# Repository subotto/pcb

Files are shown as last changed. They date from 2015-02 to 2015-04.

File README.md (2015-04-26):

# pcb
Progetto in EAGLE-EAD per la scheda integrata
situazione (26/04/15)

Il repo contiene tre progetti Eagle (la versione freeware non mi consente di riunirli in uno solo, per ora)
- power_board: è la scheda di alimenazione PoE, già stampata e realizzata. L'abbiamo usata l'ultima volta.
- sub_081 / 082: sono gli schemi per i nuovi circuiti delle fotocellule ideati da Francesco Hoch e sviluppati da lui e me. Lo schema 081 implementa l'amplificatore / comparatore con due opamp (TL081), lo schema 082 li riunisce in un singolo integrato (TL082) per economia di spazio e di costi. Prima della 24ore lo schema è stato testato con successo su breadboard (con due uA741, perché quello avevamo), ma non ho fatto in tempo a finire di diseagnare e realizzare la scheda completa e dunque abbiamo ripiegato su quelle di Guatieri, come ben ricordate.

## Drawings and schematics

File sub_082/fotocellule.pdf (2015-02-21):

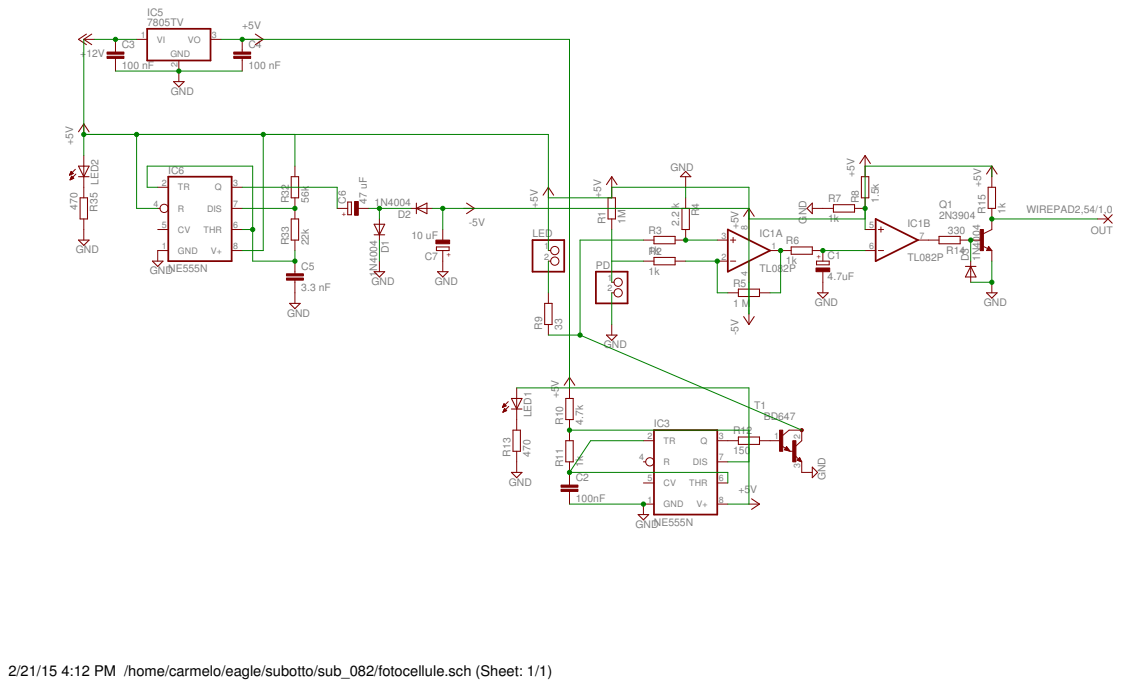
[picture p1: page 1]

2/21/15 4:12 PM /home/carmelo/eagle/subotto/sub_082/fotocellule.sch (Sheet: 1/1)

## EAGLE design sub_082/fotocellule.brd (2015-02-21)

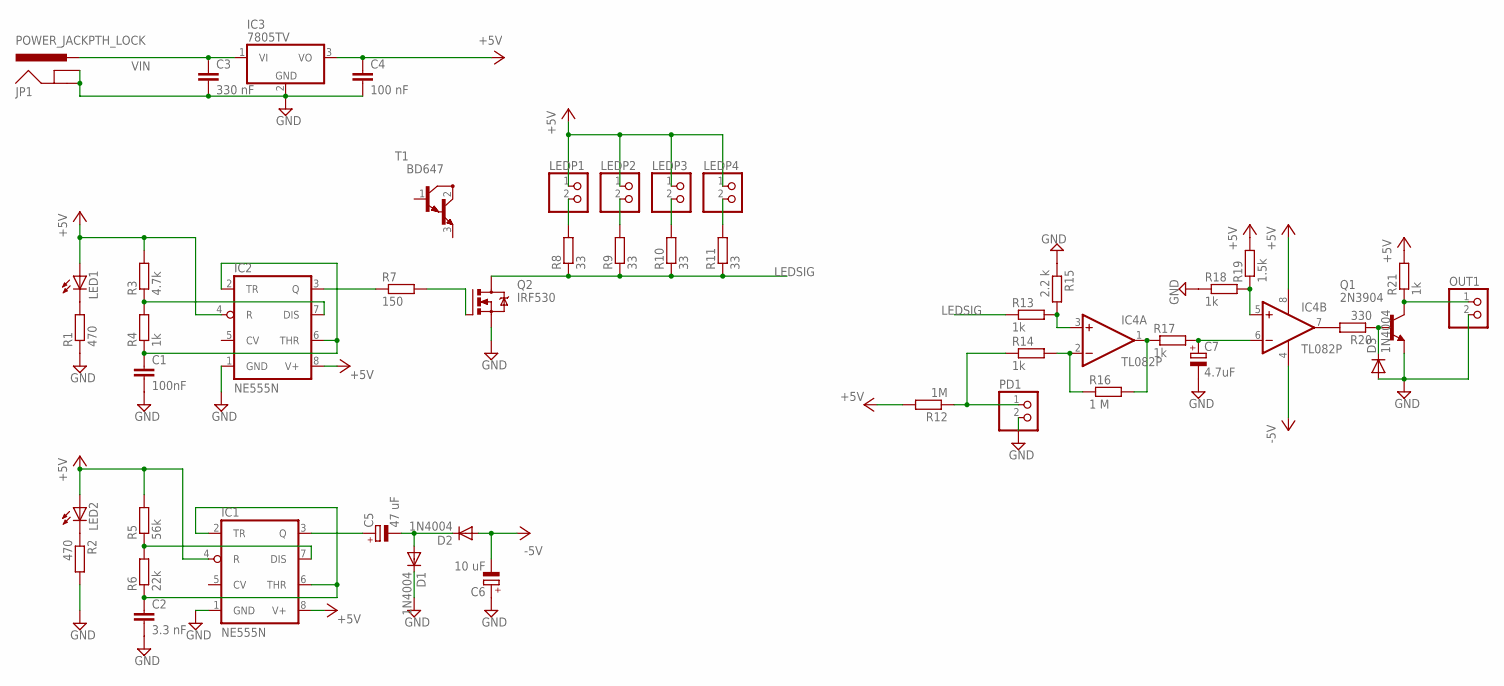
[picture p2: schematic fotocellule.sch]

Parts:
C1: 100nF; C025-024X044
C2: 3.3 nF; C025-024X044
C3: 330 nF; C025-024X044
C4: 100 nF; C025-024X044
C5: 47 uF; E2,5-5
C6: 10 uF; E2,5-5
C7: 4.7uF; E2,5-6
D1, D2, D3: 1N4004; DO41-10
IC1, IC2: NE555N; DIL08
IC3: 7805TV; TO220V
IC4: TL082P; DIL08
JP1: POWER_JACKPTH_LOCK; POWER_JACK_PTH_LOCK
LED1, LED2: LED5MM
LEDP1, LEDP2, LEDP3, LEDP4: PINHD-1X2; 1X02
OUT1: PINHD-1X2; 1X02
PD1: PINHD-1X2; 1X02
Q1: 2N3904; TO92
Q2: IRF530; TO220BV
R1, R2: 470; 0207/10
R3: 4.7k; 0207/10
R4, R13, R14, R17, R18, R21: 1k; 0207/10
R5: 56k; 0207/10
R6: 22k; 0207/10
R7: 150; 0207/10
R8, R9, R10, R11: 33; 0207/10
R12: 1M; 0207/10
R15: 2.2 k; 0207/10
R16: 1 M; 0207/10
R19: 1.5k; 0207/10
R20: 330; 0207/10
T1: BD647; TO220

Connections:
+5V: C4.1, IC1.4 (R), IC1.8 (V+), IC2.4 (R), IC2.8 (V+), IC3.3 (VO), IC4.8 (V+), LED1.A, LED2.A, LEDP1.1, LEDP2.1, LEDP3.1, LEDP4.1, R3.2, R5.2, R12.2, R19.2, R21.2
-5V: C6.-, D2.A, IC4.4 (V-)
GND: C1.2, C2.2, C3.2, C4.2, C6.+, C7.-, D1.C, D3.A, IC1.1 (GND), IC2.1 (GND), IC3.2 (GND), JP1.GND, JP1.GNDBREAK, OUT1.2, PD1.2, Q1.3 (E), Q2.S, R1.1, R2.2, R15.1, R18.1
LEDSIG: Q2.D, R8.1, R9.1, R10.1, R11.1, R13.1
unnamed: C1.1, IC2.2 (TR), IC2.6 (THR), R4.1
unnamed: IC2.7 (DIS), R3.1, R4.2
unnamed: IC4.3 (+IN), R13.2, R15.2
unnamed: IC4.1 (OUT), R16.2, R17.1
unnamed: C7.+, IC4.6 (-IN), R17.2
unnamed: IC4.5 (+IN), R18.2, R19.1
unnamed: C2.1, IC1.2 (TR), IC1.6 (THR), R6.1
unnamed: IC1.7 (DIS), R5.1, R6.2
unnamed: IC2.3 (Q), R7.1
unnamed: C5.+, IC1.3 (Q)
unnamed: C5.-, D1.A, D2.C
unnamed: Q2.G, R7.2
unnamed: IC4.7 (OUT), R20.2
unnamed: LED1.K (C), R1.2
unnamed: LEDP1.2, R8.2
unnamed: OUT1.1, Q1.1 (C), R21.1
unnamed: LEDP2.2, R9.2
unnamed: D3.C, Q1.2 (B), R20.1
unnamed: LEDP3.2, R10.2
unnamed: LEDP4.2, R11.2
unnamed: IC4.2 (-IN), R14.2, R16.1
unnamed: PD1.1, R12.1, R14.1
unnamed: LED2.K (C), R2.1
VIN: C3.1, IC3.1 (VI), JP1.PWR

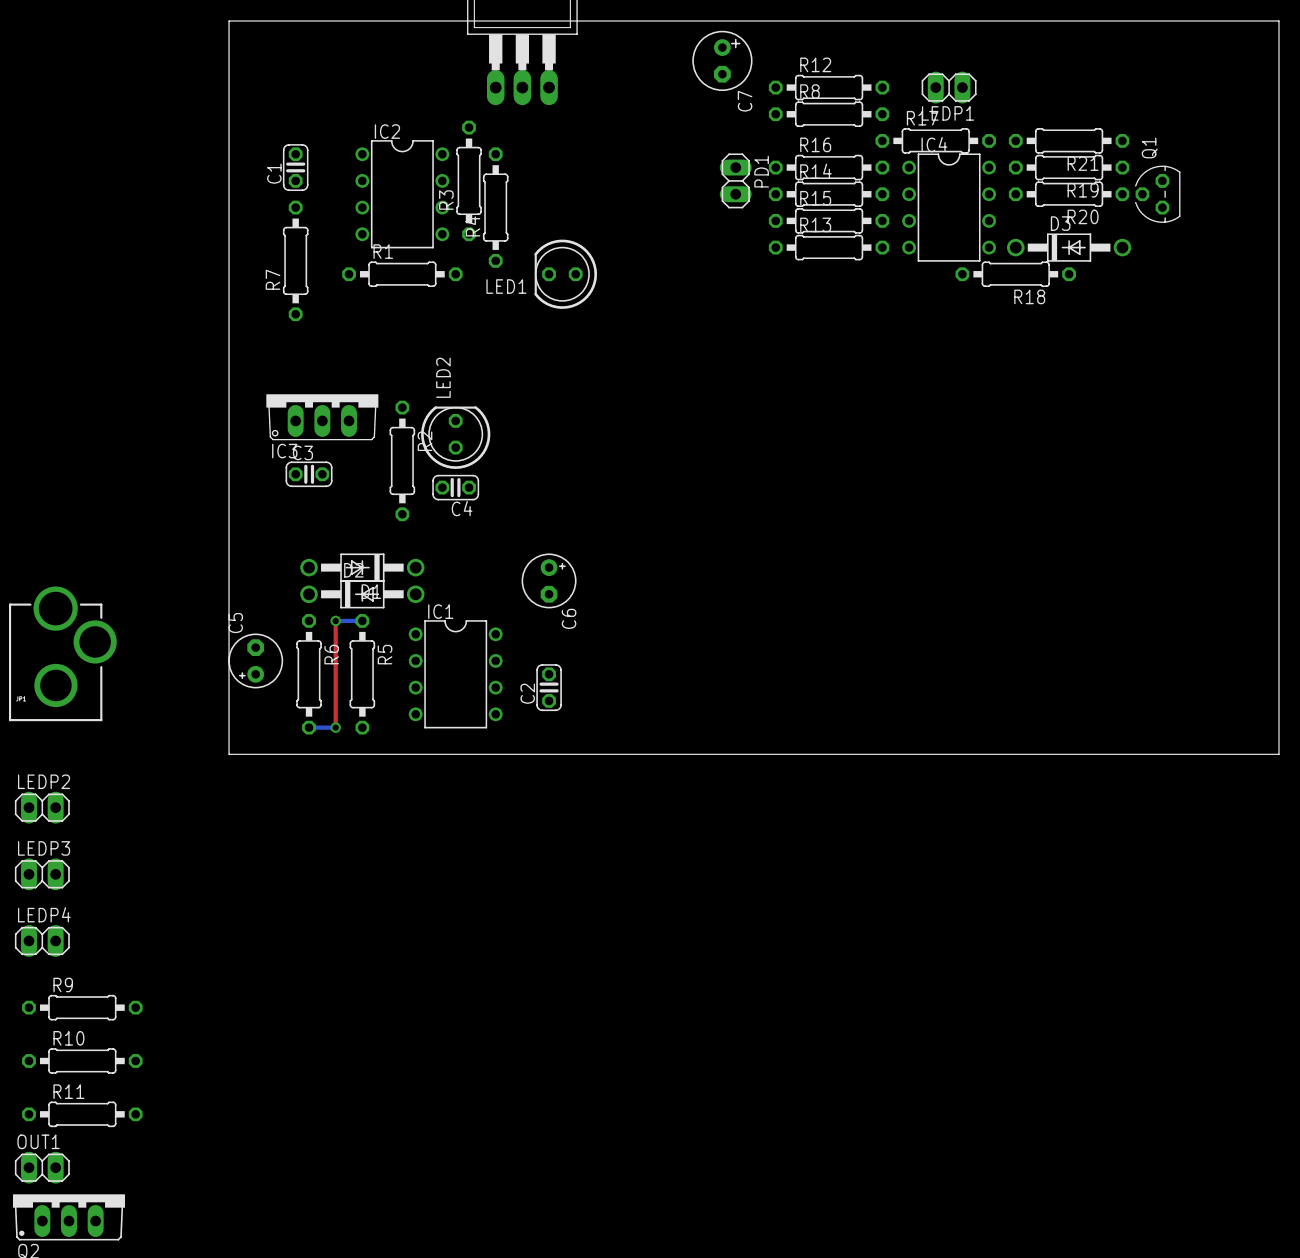
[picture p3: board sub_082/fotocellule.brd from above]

Board: 2 copper layers, 100.0 x 69.8 mm, 47 parts (0 on the bottom side), 28 nets.

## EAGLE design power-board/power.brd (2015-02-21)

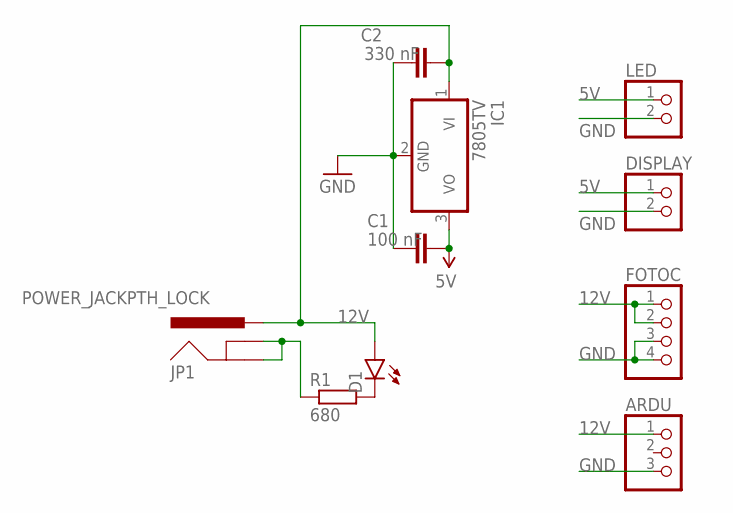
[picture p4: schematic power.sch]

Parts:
ARDU: PINHD-1X3; 1X03
C1: 100 nF; C025-025X050
C2: 330 nF; C025-025X050
D1: LED5MM
DISPLAY: PINHD-1X2; 1X02
FOTOC: PINHD-1X4; 1X04
IC1: 7805TV; TO220V
JP1: POWER_JACKPTH_LOCK; POWER_JACK_PTH_LOCK
LED: PINHD-1X2; 1X02
R1: 680; 0207/10

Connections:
5V: C1.1, DISPLAY.1, IC1.3 (VO), LED.1
12V: ARDU.1, C2.2, D1.A, FOTOC.1, FOTOC.2, IC1.1 (VI), JP1.PWR
GND: ARDU.3, C1.2, C2.1, DISPLAY.2, FOTOC.3, FOTOC.4, IC1.2 (GND), JP1.GND, JP1.GNDBREAK, LED.2, R1.1
unnamed: D1.K (C), R1.2

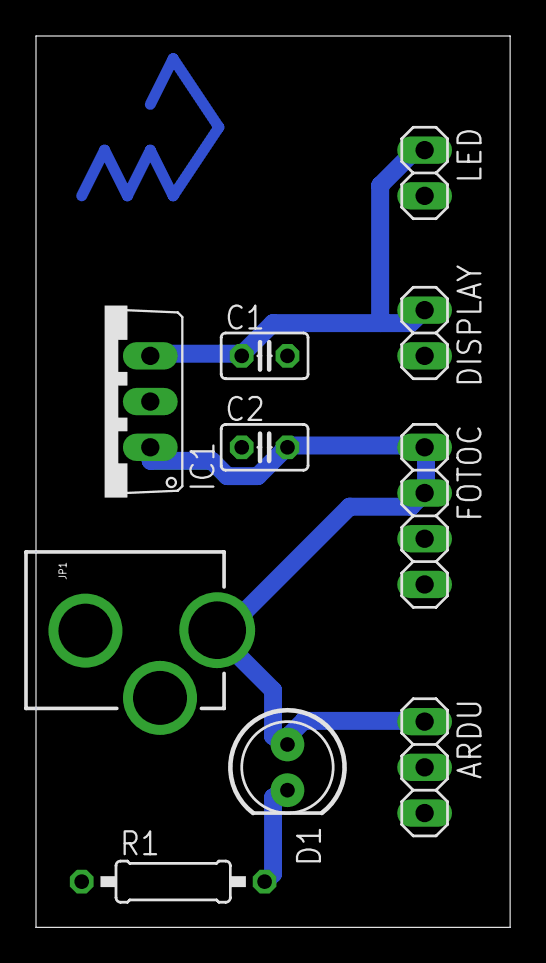
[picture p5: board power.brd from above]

Board: 2 copper layers, 26.3 x 49.5 mm, 10 parts (0 on the bottom side), 4 nets.

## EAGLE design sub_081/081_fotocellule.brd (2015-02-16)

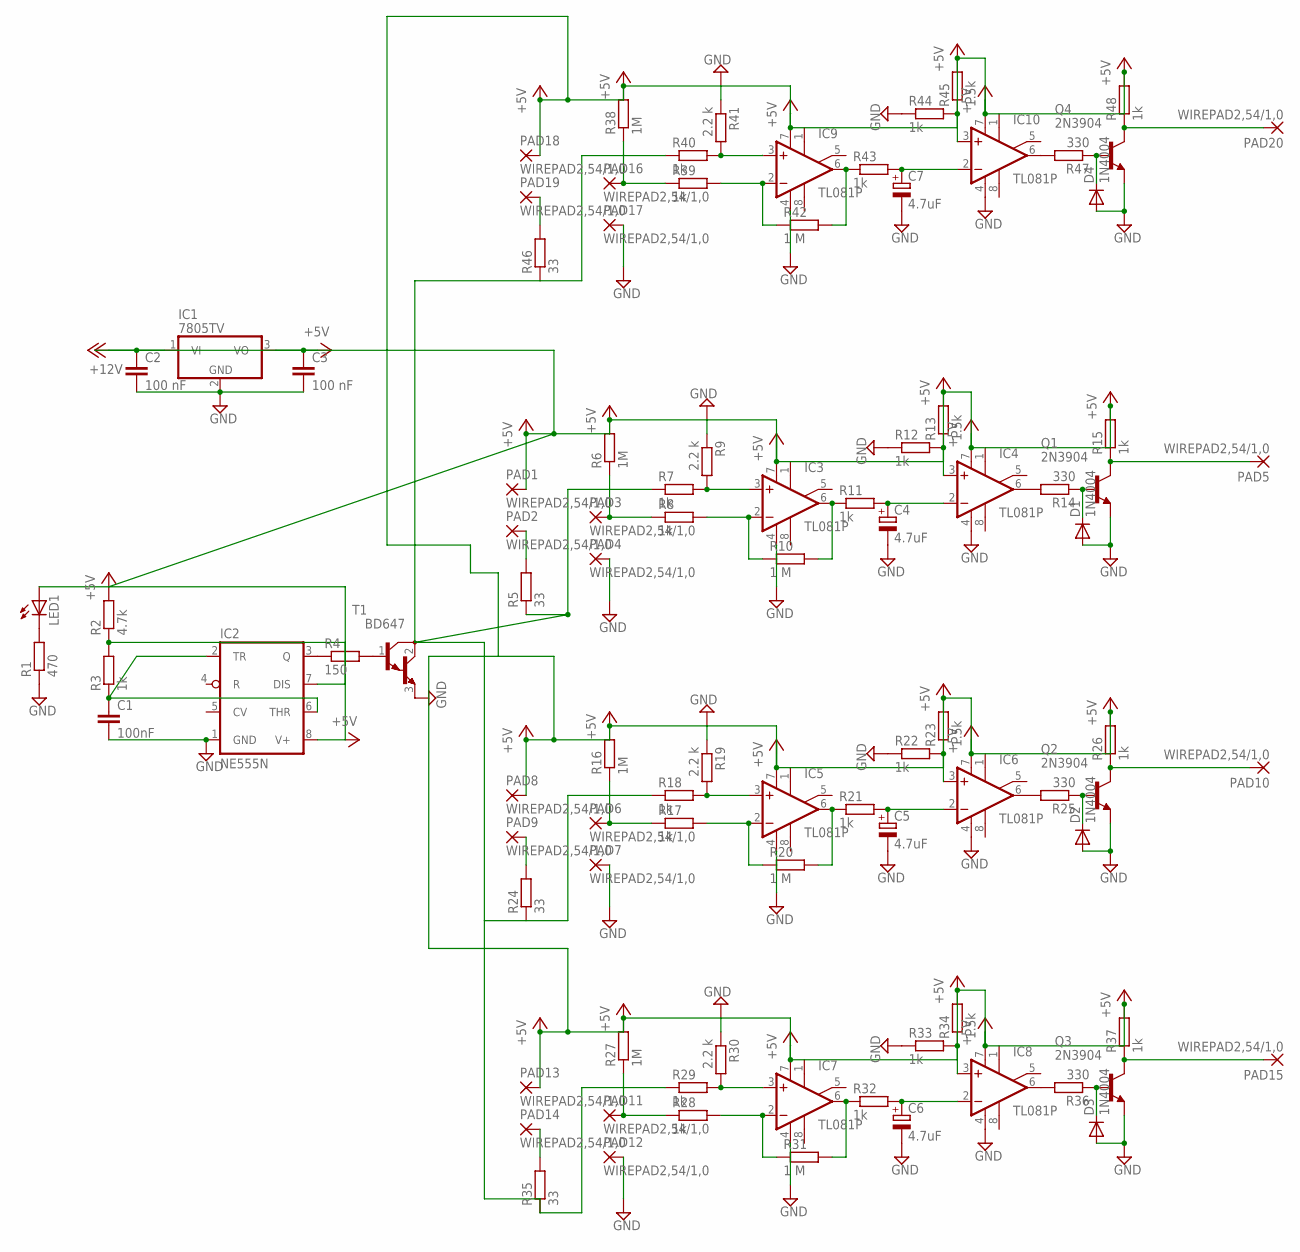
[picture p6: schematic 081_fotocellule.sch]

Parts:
C1: 100nF; C025-024X044
C2, C3: 100 nF; C025-024X044
C4, C5, C6, C7: 4.7uF; E2,5-6
D1, D2, D3, D4: 1N4004; DO41-10
IC1: 7805TV; TO220V
IC2: NE555N; DIL08
IC3, IC4, IC5, IC6, IC7, IC8, IC9, IC10: TL081P; DIL08
LED1: LED5MM
PAD1, PAD2, PAD3, PAD4, PAD5, PAD6, PAD7, PAD8, PAD9, PAD10, PAD11, PAD12, PAD13, PAD14, PAD15, PAD16, PAD17, PAD18, PAD19, PAD20: WIREPAD2,54/1,0; 2,54/1,0
Q1, Q2, Q3, Q4: 2N3904; TO92
R1: 470; 0207/10
R2: 4.7k; 0207/10
R3, R7, R8, R11, R12, R15, R17, R18, R21, R22, R26, R28, R29, R32, R33, R37, R39, R40, R43, R44, R48: 1k; 0207/10
R4: 150; 0207/10
R5, R24, R35, R46: 33; 0207/10
R6, R16, R27, R38: 1M; 0207/10
R9, R19, R30, R41: 2.2 k; 0207/10
R10, R20, R31, R42: 1 M; 0207/10
R13, R23, R34, R45: 1.5k; 0207/10
R14, R25, R36, R47: 330; 0207/10
T1: BD647; TO220

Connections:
+5V: C3.1, IC1.3 (VO), IC2.8 (V+), IC3.7 (V+), IC4.7 (V+), IC5.7 (V+), IC6.7 (V+), IC7.7 (V+), IC8.7 (V+), IC9.7 (V+), IC10.7 (V+), LED1.A, PAD1.1, PAD8.1, PAD13.1, PAD18.1, R2.2, R6.2, R13.2, R15.2, R16.2, R23.2, R26.2, R27.2, R34.2, R37.2, R38.2, R45.2, R48.2
GND: C1.2, C2.2, C3.2, C4.-, C5.-, C6.-, C7.-, D1.A, D2.A, D3.A, D4.A, IC1.2 (GND), IC2.1 (GND), IC3.4 (V-), IC4.4 (V-), IC5.4 (V-), IC6.4 (V-), IC7.4 (V-), IC8.4 (V-), IC9.4 (V-), IC10.4 (V-), PAD4.1, PAD7.1, PAD12.1, PAD17.1, Q1.3 (E), Q2.3 (E), Q3.3 (E), Q4.3 (E), R1.1, R9.1, R12.1, R19.1, R22.1, R30.1, R33.1, R41.1, R44.1, T1.3 (E)
unnamed: PAD3.1, R6.1, R8.1
unnamed: IC3.2 (-IN), R8.2, R10.1
unnamed: IC3.3 (+IN), R7.2, R9.2
unnamed: IC3.6 (OUT), R10.2, R11.1
unnamed: C4.+, IC4.2 (-IN), R11.2
unnamed: IC4.3 (+IN), R12.2, R13.1
unnamed: PAD2.1, R5.2
unnamed: PAD6.1, R16.1, R17.1
unnamed: IC2.3 (Q), R4.1
unnamed: C1.1, IC2.2 (TR), IC2.6 (THR), R3.1
unnamed: IC4.6 (OUT), R14.2
unnamed: R4.2, T1.1 (B)
unnamed: IC5.2 (-IN), R17.2, R20.1
unnamed: LED1.K (C), R1.2
unnamed: IC2.7 (DIS), R2.1, R3.2
unnamed: PAD5.1, Q1.1 (C), R15.1
unnamed: IC5.3 (+IN), R18.2, R19.2
unnamed: D1.C, Q1.2 (B), R14.1
unnamed: IC5.6 (OUT), R20.2, R21.1
unnamed: C5.+, IC6.2 (-IN), R21.2
unnamed: IC6.3 (+IN), R22.2, R23.1
unnamed: PAD9.1, R24.2
unnamed: PAD10.1, Q2.1 (C), R26.1
unnamed: D2.C, Q2.2 (B), R25.1
unnamed: IC6.6 (OUT), R25.2
unnamed: PAD11.1, R27.1, R28.1
unnamed: IC7.2 (-IN), R28.2, R31.1
unnamed: IC7.3 (+IN), R29.2, R30.2
unnamed: IC7.6 (OUT), R31.2, R32.1
unnamed: C6.+, IC8.2 (-IN), R32.2
unnamed: IC8.3 (+IN), R33.2, R34.1
unnamed: PAD14.1, R35.2
unnamed: PAD15.1, Q3.1 (C), R37.1
unnamed: D3.C, Q3.2 (B), R36.1
unnamed: IC8.6 (OUT), R36.2
unnamed: PAD16.1, R38.1, R39.1
unnamed: IC9.2 (-IN), R39.2, R42.1
unnamed: IC9.3 (+IN), R40.2, R41.2
unnamed: IC9.6 (OUT), R42.2, R43.1
unnamed: C7.+, IC10.2 (-IN), R43.2
unnamed: IC10.3 (+IN), R44.2, R45.1
unnamed: PAD19.1, R46.2
unnamed: R5.1, R7.1, R18.1, R24.1, R29.1, R35.1, R40.1, R46.1, T1.2 (C)
unnamed: PAD20.1, Q4.1 (C), R48.1
unnamed: D4.C, Q4.2 (B), R47.1
unnamed: IC10.6 (OUT), R47.2
VCC: C2.1, IC1.1 (VI)

Board: 2 copper layers, 95 parts (0 on the bottom side), 49 nets, no tracks yet.

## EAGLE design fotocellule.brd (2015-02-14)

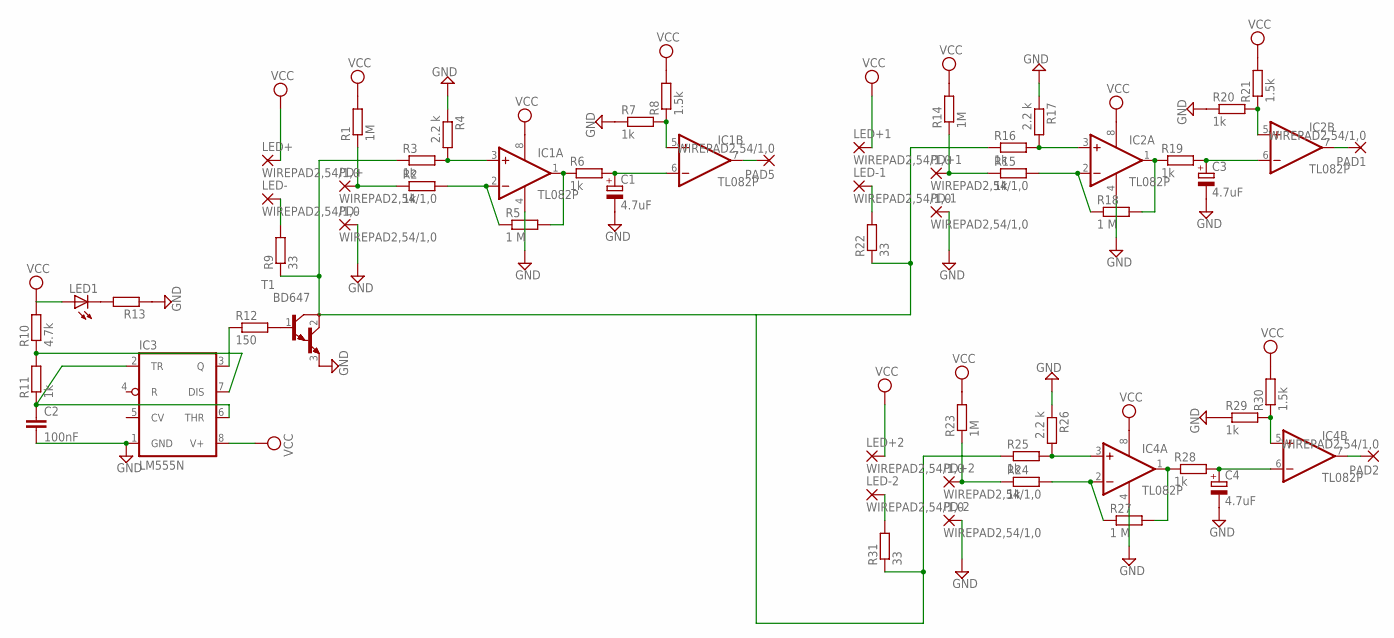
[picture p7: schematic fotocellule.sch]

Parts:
C1, C3, C4: 4.7uF; E2,5-6
C2: 100nF; C025-024X044
IC1, IC2, IC4: TL082P; DIL08
IC3: LM555N; DIL08
LED1: LED5MM
LED+, LED+1, LED+2: WIREPAD2,54/1,0; 2,54/1,0
LED-, LED-1, LED-2: WIREPAD2,54/1,0; 2,54/1,0
PAD1, PAD2, PAD5: WIREPAD2,54/1,0; 2,54/1,0
PD+, PD+1, PD+2: WIREPAD2,54/1,0; 2,54/1,0
PD-, PD-1, PD-2: WIREPAD2,54/1,0; 2,54/1,0
R1, R14, R23: 1M; 0207/10
R2, R3, R6, R7, R11, R15, R16, R19, R20, R24, R25, R28, R29: 1k; 0207/10
R4, R17, R26: 2.2 k; 0207/10
R5, R18, R27: 1 M; 0207/10
R8, R21, R30: 1.5k; 0207/10
R9, R22, R31: 33; 0207/10
R10: 4.7k; 0207/10
R12: 150; 0207/10
R13: R-EU_0207/10; 0207/10
T1: BD647; TO220

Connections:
GND: C1.-, C2.2, C3.-, C4.-, IC1.4 (V-), IC2.4 (V-), IC3.1 (GND), IC4.4 (V-), PD-.1, PD-1.1, PD-2.1, R4.1, R7.1, R13.1, R17.1, R20.1, R26.1, R29.1, T1.3 (E)
unnamed: PD+.1, R1.1, R2.1
unnamed: IC1.2 (-IN), R2.2, R5.1
unnamed: IC1.3 (+IN), R3.2, R4.2
unnamed: IC1.1 (OUT), R5.2, R6.1
unnamed: C1.+, IC1.6 (-IN), R6.2
unnamed: IC1.5 (+IN), R7.2, R8.1
unnamed: LED-.1, R9.2
unnamed: IC3.3 (Q), R12.1
unnamed: C2.1, IC3.2 (TR), IC3.6 (THR), R11.1
unnamed: IC3.7 (DIS), R10.1, R11.2
unnamed: R12.2, T1.1 (B)
unnamed: IC1.7 (OUT), PAD5.1
unnamed: LED1.K (C), R13.2
unnamed: PD+1.1, R14.1, R15.1
unnamed: IC2.2 (-IN), R15.2, R18.1
unnamed: IC2.3 (+IN), R16.2, R17.2
unnamed: IC2.1 (OUT), R18.2, R19.1
unnamed: C3.+, IC2.6 (-IN), R19.2
unnamed: IC2.5 (+IN), R20.2, R21.1
unnamed: LED-1.1, R22.2
unnamed: R3.1, R9.1, R16.1, R22.1, R25.1, R31.1, T1.2 (C)
unnamed: IC2.7 (OUT), PAD1.1
unnamed: PD+2.1, R23.1, R24.1
unnamed: IC4.2 (-IN), R24.2, R27.1
unnamed: IC4.3 (+IN), R25.2, R26.2
unnamed: IC4.1 (OUT), R27.2, R28.1
unnamed: C4.+, IC4.6 (-IN), R28.2
unnamed: IC4.5 (+IN), R29.2, R30.1
unnamed: LED-2.1, R31.2
unnamed: IC4.7 (OUT), PAD2.1
VCC: IC1.8 (V+), IC2.8 (V+), IC3.8 (V+), IC4.8 (V+), LED1.A, LED+.1, LED+1.1, LED+2.1, R1.2, R8.2, R10.2, R14.2, R21.2, R23.2, R30.2

Board: 2 copper layers, 56 parts (0 on the bottom side), 32 nets, no tracks yet.

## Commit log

2015-02-14 First commit: scheda fotocellule con TL082
    [fotocellule.brd, fotocellule.sch]
2015-02-16 Risistemati i due progetti per l'utilizzo dei singoli/doppi opamp
    [081_fotocellule.brd, 081_fotocellule.sch, fotocellule.brd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]
2015-02-17 Power board added
    [power.brd, power.sch]
2015-02-17 power board ok
    [power.brd, power.sch]
2015-02-17 Power board printed
    [power.brd, power.sch]
2015-02-21 Learned how to use net (instead of wires) cleaned connections in schematic made ground plane a real GND routed like a boss \m/
    [power.brd, power.sch]
2015-02-21 modificato gitignore per i file di eagle
2015-02-21 Rewired correctly sub082
    [fotocellule.brd, fotocellule.sch]

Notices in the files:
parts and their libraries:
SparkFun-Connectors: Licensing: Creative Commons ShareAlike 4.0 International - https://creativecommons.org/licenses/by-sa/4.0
